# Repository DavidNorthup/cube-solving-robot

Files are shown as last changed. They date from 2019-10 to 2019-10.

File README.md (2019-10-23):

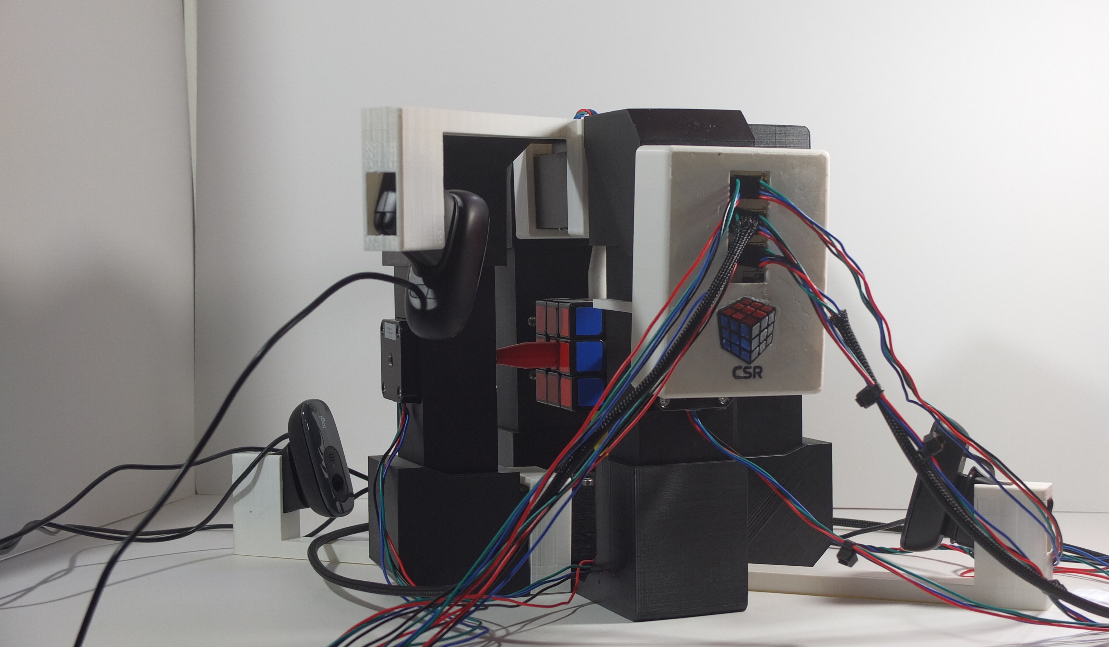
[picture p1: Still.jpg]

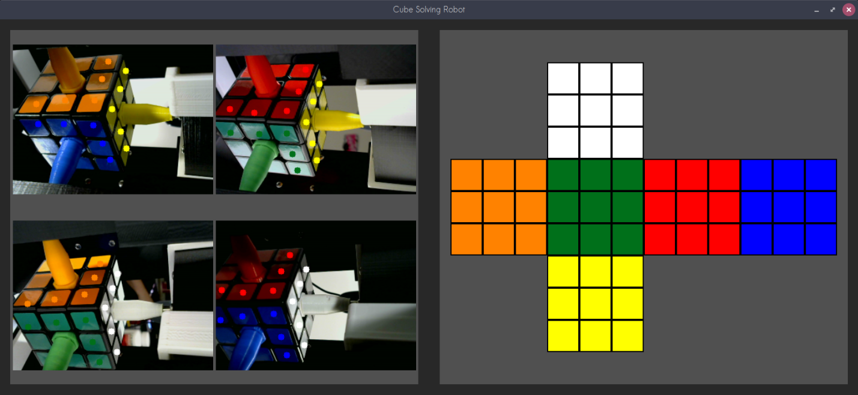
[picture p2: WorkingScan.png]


# cube-solving-robot
A personal project involving building a robot that solves the rubik's cube puzzle. There are three major components to this project. There are the robot parts themselves, the arduino code that controls the motion of the robot, and the desktop application that is used to control the robot and solve the puzzles. The application software and additional arduino libraries are written in c++. There are also a few utilities that I have included to make certain tasks more automatic. View a solve [here](https://youtu.be/WDEkHynfurc).

# Dependencies:
The arduino itself is only dependent on the arduino libraries included with the default IDE. 

The desktop application requires the following additional libraries:
[OpenCV](https://opencv.org/), [SFML](https://www.sfml-dev.org/), and [ckociemba](https://github.com/muodov/kociemba), a fast implementation of the two phase algorithm for solving rubik's cube puzzles.

# Utilities

The utilities that I have included to make tasks easier are the Sampling helper (compiled with make sampling-config.exe) and the Mask Viewer (compiled with make training-mask.exe).

## Sampling Helper
This file is meant to be run with an image captured from the webcam you are attempting to pinpoint sampling centers from. The inteded usage is to create a file that can be read on startup with the locations of points that are relevant to the scanning of the cube. For example: If you run the main desktop application, and press ctrl + s, the application will save the captured frame from the wecam to a file called "sample.jpg". Then if you wanted to create a locations file called "sampling-locations.dat" you could simply run the command: "./sampling-config.exe sample_flu.jpg > sampling-locations-flu.dat". Then when the image appears, click on the points that you wish to be sampling locations, and then close the window.

## Mask Viewer
The current implementation of the software uses opencv to select ranges of pixels defined by HSV value bounds in "Camera.h" for each of the colors on the cube. Opencv iterates through the image once for each color and generates a binary matrix of pixels with value 0 everywhere any given pixel is outside of the bounds for the speicifed color. Then it uses the sampling centers to count the number of pixels in range inside each circle defined by the center and a radius that match each color. The software then counts the number of matches for each color and whichever is highest is determined as the color for that point. This utility allows you to see the masks for a given sample image, and then reveals what it would conclude given the current bounds. Example usage is: ./training-mask.exe [image_file] [sampling locations].

# Installation Details:
1.) The first step is to install opencv, I used [this page](https://docs.opencv.org/master/d7/d9f/tutorial_linux_install.html).

2.) Install SFML, I used my package manager to install using: apt-get install libsfml-dev.

3.) Clone this repository and the kociemba repository, and make the target within 'ckociemba'.

4.) Place the executable compiled in hte step prior into the application directory.

5.) Compile all of the executables within the application directory.

6.) Install the arduino software on the boards, with the sketch and libraries included.

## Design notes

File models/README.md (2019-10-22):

# Building the robot.
I created all of these models from scratch using Autodesk Fusion 360 in parametric mode. I printed all of the parts on a Creality CR-10.

## Parts required
* 6 Main Body
* 4 Connector
* 2 Connector Loose
* 6 Cube Turner Tri Fork
* 6 Axel Tri Forks
* 2 Camera Mounts
* 2 Flipped Camera Mounts

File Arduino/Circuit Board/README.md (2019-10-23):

This folder contains the files that I used to get the PCB for the arduino and motor controllers designed and fabricated.

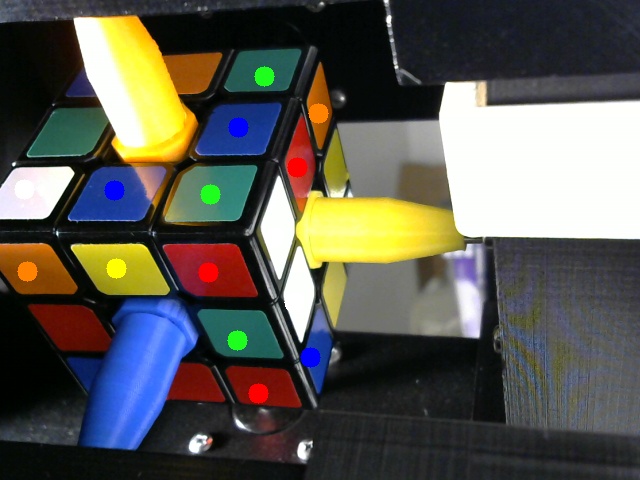
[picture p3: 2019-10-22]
application/sample.jpg

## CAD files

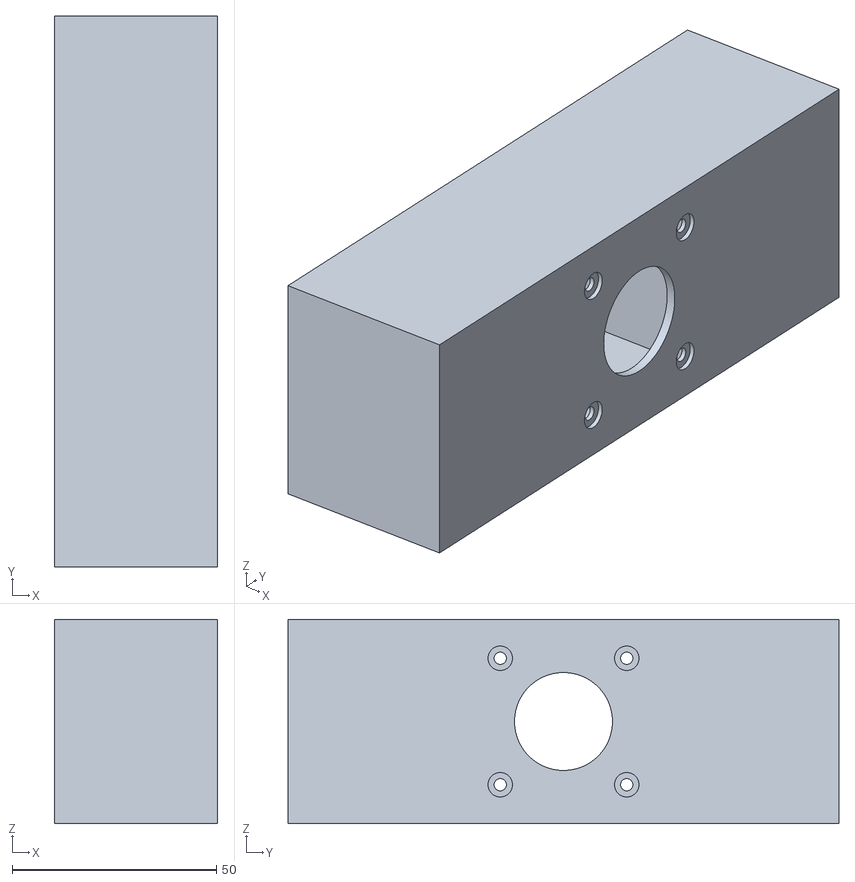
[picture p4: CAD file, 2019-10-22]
models/Main Body.stl
40.0 x 135.0 x 50.0

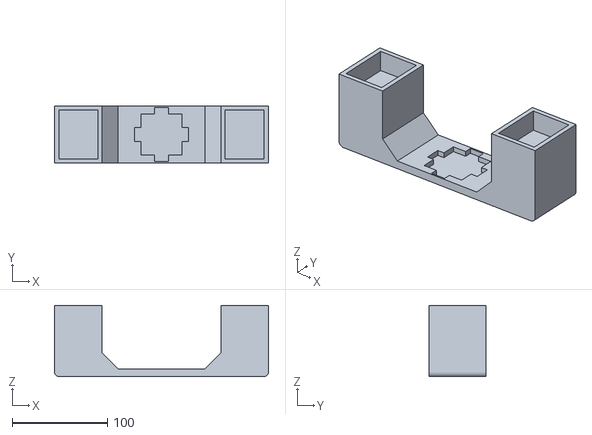
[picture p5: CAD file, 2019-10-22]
models/Connector Loose.stl
225.0 x 60.0 x 75.0

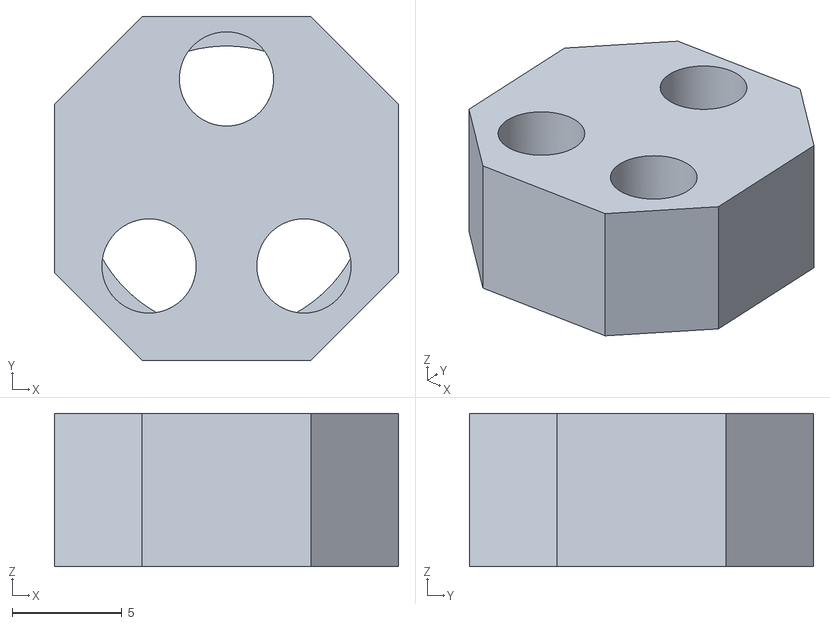
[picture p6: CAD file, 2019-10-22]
models/Cube Turner Tri Fork.stl
15.7 x 15.7 x 7.00

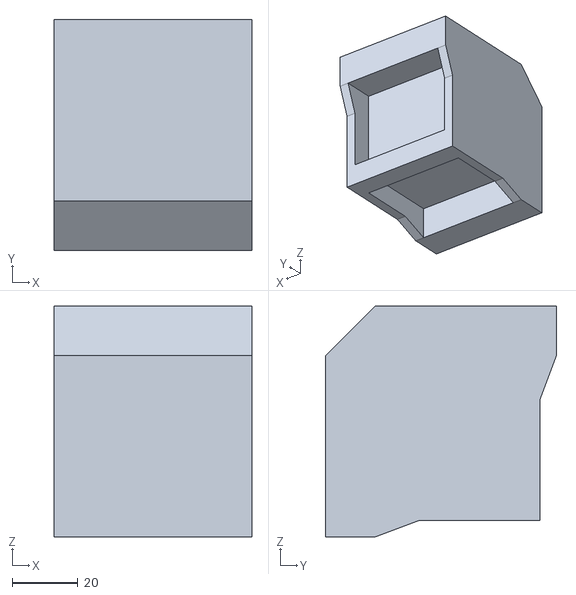
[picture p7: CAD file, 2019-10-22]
models/Connector.stl
60.0 x 70.0 x 70.0

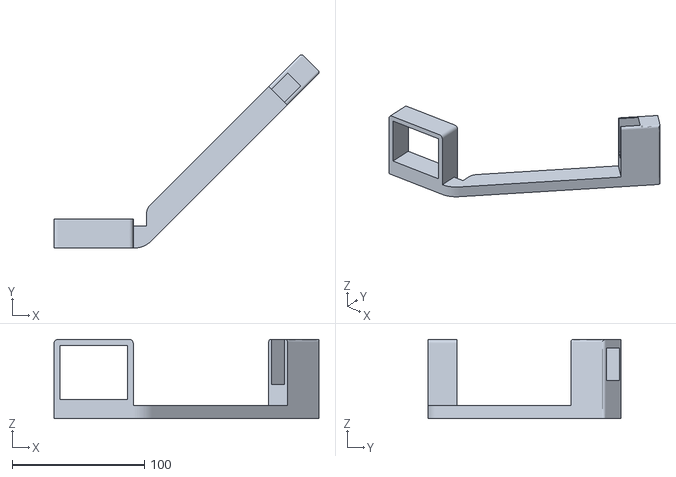
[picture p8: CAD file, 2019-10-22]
models/Camera_Mount.stl
200.6 x 146.5 x 60.0

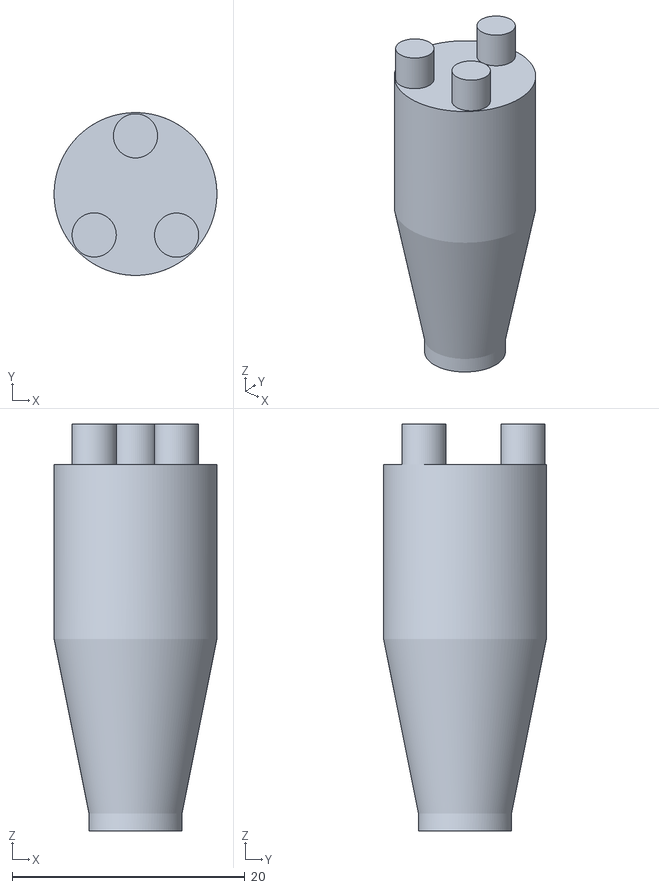
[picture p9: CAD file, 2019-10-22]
models/Axel Tri Fork.stl
14.0 x 14.0 x 35.0

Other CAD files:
models/Camera_Mount_Flipped.stl

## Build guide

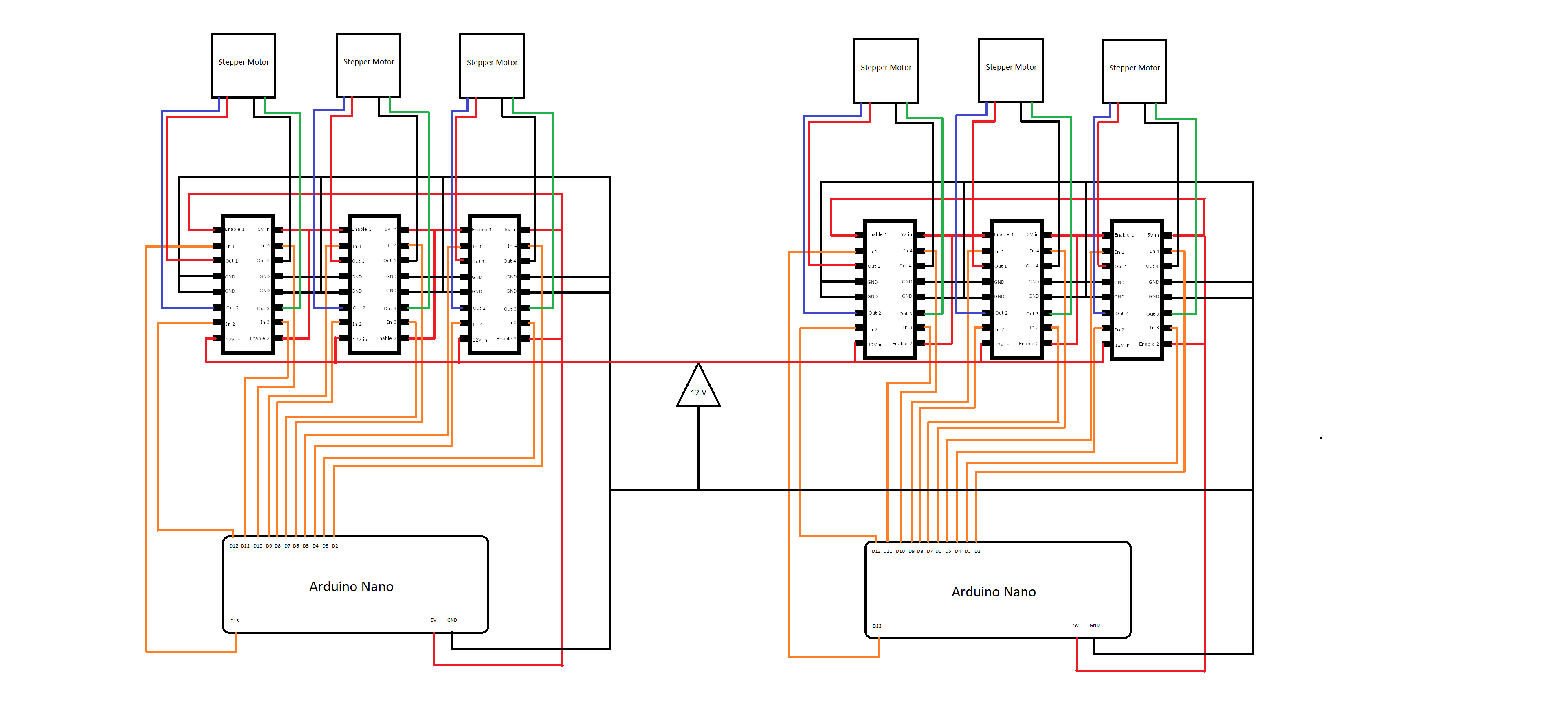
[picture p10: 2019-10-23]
Arduino/Circuit Board/Full Setup.png

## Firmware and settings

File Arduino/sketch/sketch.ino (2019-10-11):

#include <MyStepper.h>

#define STEPS_PER_QUARTER_TURN 50

int identifier = 1; // 1 for LR, 2 for FB

int motor1_pins[] = {10,12,11,13};
int motor2_pins[] = {9,7,8,6};
int motor3_pins[] = {2,4,3,5};

StepperMotor motor1(motor1_pins);
StepperMotor motor2(motor2_pins);
StepperMotor motor3(motor3_pins);

void setup() {
  // put your setup code here, to run once:
  for (int i = 0; i < PINS_PER_STEPPER; i++) {
    pinMode(motor1_pins[i], OUTPUT);
    pinMode(motor2_pins[i], OUTPUT);
    pinMode(motor3_pins[i], OUTPUT);  
  }
  Serial.begin(9600);
}

void loop() {
  if (Serial.available()) {
    int num_read = Serial.read();
    if (num_read != 255) {
      // Parse the message
      int motor_index = num_read & 3;
      bool dir_clockwise = ((num_read & 4) >> 2) == 1;
      int quarter_turns = (num_read >> 3);

      if (motor_index == 0) {
        motor1.step(dir_clockwise, quarter_turns * STEPS_PER_QUARTER_TURN);
      }
      if (motor_index == 1) {
        motor2.step(dir_clockwise, quarter_turns * STEPS_PER_QUARTER_TURN);
      }
      if (motor_index == 2) {
        motor3.step(dir_clockwise, quarter_turns * STEPS_PER_QUARTER_TURN);  
      }
      if (motor_index == 3) {
        if (dir_clockwise) {
          StepperMotor::step_two_motors(motor3, motor2, quarter_turns * 50);
        } else {
          StepperMotor::step_two_motors(motor2, motor3, quarter_turns * 50);
        }
      }
      Serial.print((char) num_read);
    } else {
      Serial.print((char)identifier);  
    }  
  }
}

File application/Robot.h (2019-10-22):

/*
This file implements all of the specific information that is going to be needed in order
to control the robot implementation. It is designed to interface the rest of the application
to the CSR robot itself.

*/

#include "SerialCommunication.h"
#include <stdlib.h>

// This number represents the minimum number of microseconds to pause to allow the arduino's 
// to reset after connecting to them.
#define PAUSE_DURATION 3*1000*1000

// These two macros are the expected values when we ping 
// the SerialManagers with message value "IDENTIFICATION_PACKET", and are
// used to determine which arduino is which, regardless of what ports they are plugged into.
#define LR_IDENTIFIER 1
#define FB_IDENTIFIER 2

// The following macros are values that can be added together in order to form a command 
// that fits within one byte.

// The two least significant bits index the motor within the controller [1-3]
#define MOTOR_1 0
#define MOTOR_2 1
#define MOTOR_3 2

// The next least significant bit identifies the direction of travel
#define DIRECTION_CLOCKWISE 0
#define DIRECTION_COUNTERCLOCKWISE (1 << 2)

// The remaining bits store the number of quarter turns desired, or in the case
// of zero, the special value used by the separator motors for separation purposes
// in the slower (ruku style) configuration. 
#define ONE_QUARTER_TURN (1 << 3)
#define TWO_QUARTER_TURNS (2 << 3)
#define THREE_QUARTER_TURNS (3 << 3)
#define FOUR_QUARTER_TURNS (4 << 3)

// Definitions for all of the valid cube moves
#define MOVE_R MOTOR_3 + DIRECTION_CLOCKWISE + ONE_QUARTER_TURN, LR_IDENTIFIER
#define MOVE_R_PRIME MOTOR_3 + DIRECTION_COUNTERCLOCKWISE + ONE_QUARTER_TURN, LR_IDENTIFIER
#define MOVE_R2 MOTOR_3 + DIRECTION_CLOCKWISE + TWO_QUARTER_TURNS, LR_IDENTIFIER

#define MOVE_L MOTOR_2 + DIRECTION_COUNTERCLOCKWISE + ONE_QUARTER_TURN, LR_IDENTIFIER
#define MOVE_L_PRIME MOTOR_2 + DIRECTION_CLOCKWISE + ONE_QUARTER_TURN, LR_IDENTIFIER
#define MOVE_L2 MOTOR_2 + DIRECTION_CLOCKWISE + TWO_QUARTER_TURNS, LR_IDENTIFIER

#define MOVE_U MOTOR_1 + DIRECTION_CLOCKWISE + ONE_QUARTER_TURN, LR_IDENTIFIER
#define MOVE_U_PRIME MOTOR_1 + DIRECTION_COUNTERCLOCKWISE + ONE_QUARTER_TURN, LR_IDENTIFIER
#define MOVE_U2 MOTOR_1 + DIRECTION_CLOCKWISE + TWO_QUARTER_TURNS, LR_IDENTIFIER

#define MOVE_F MOTOR_3 + DIRECTION_CLOCKWISE + ONE_QUARTER_TURN, FB_IDENTIFIER
#define MOVE_F_PRIME MOTOR_3 + DIRECTION_COUNTERCLOCKWISE + ONE_QUARTER_TURN, FB_IDENTIFIER
#define MOVE_F2 MOTOR_3 + DIRECTION_CLOCKWISE + TWO_QUARTER_TURNS, FB_IDENTIFIER

#define MOVE_B MOTOR_2 + DIRECTION_COUNTERCLOCKWISE + ONE_QUARTER_TURN, FB_IDENTIFIER
#define MOVE_B_PRIME MOTOR_2 + DIRECTION_CLOCKWISE + ONE_QUARTER_TURN, FB_IDENTIFIER
#define MOVE_B2 MOTOR_2 + DIRECTION_COUNTERCLOCKWISE + TWO_QUARTER_TURNS, FB_IDENTIFIER

#define MOVE_D MOTOR_1 + DIRECTION_CLOCKWISE + ONE_QUARTER_TURN, FB_IDENTIFIER
#define MOVE_D_PRIME MOTOR_1 + DIRECTION_COUNTERCLOCKWISE + ONE_QUARTER_TURN, FB_IDENTIFIER
#define MOVE_D2 MOTOR_1 + DIRECTION_CLOCKWISE + TWO_QUARTER_TURNS, FB_IDENTIFIER 

#define MOVES {"R", "R'", "R2", "L", "L'", "L2", "F", "F'", "F2", "B", "B'", "B2", "U", "U'", "U2", "D", "D'", "D2"}

#define SCRAMBLE_LENGTH 20

// So for example if we wanted to perform a move on motor 2, clockwise, with 3 quarter turns,
// we would pass the following into the sendCommand function: MOTOR_2 + DIRECTION_CLOCKWISE + THREE_QUARTER_TURNS

namespace csr{

class Robot {
    public:
    Robot(std::string port1, std::string port2);
    ~Robot();
    bool sendCommand(uint16_t command, uint16_t smIdentifier);
    void performMove(std::string move);
    std::string reverseMove(std::string move);
    std::string performMoves(std::string moves);
    std::string scramble(int len);

    private:
    communication::SerialManager * lr_manager;
    communication::SerialManager * fb_manager;
};

}

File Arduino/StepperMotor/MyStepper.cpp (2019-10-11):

#include "Arduino.h"
#include "MyStepper.h"

#define STEPPER_DELAY 1500 // This is in microseconds
#define STEPPER_MIN_DELAY 500

/*
This is the constructor for the stepper motor object. There is only one 
constructor and it takes an integer array as a parameter, which corresponds
to a ordered list of pin numbers connected to the arduino, which corresponds to
the order needed to proceed in to produce motion in the clockwise direction,
so for example if we have the input:

pins_clockwise: [1,2,3,4]

Then if we activate the pins by themselves in the order 1-2-3-4,
then we produce a clockwise rotation on the motor.
*/
StepperMotor::StepperMotor(int pins_clockwise[]) {
    for(int j = 0; j < PINS_PER_STEPPER; j++) {
        this->pins_clockwise[j] = pins_clockwise[j];
        this->pins_cclockwise[j] = pins_clockwise[PINS_PER_STEPPER - 1 - j];
    }
    
    i = 0;
    for (int j = 0; j < PINS_PER_STEPPER; j++) {
        pinMode(pins_clockwise[j], OUTPUT);
    }
}

int StepperMotor::calc_delay(int x, int n) {
    double xm = x - (n/2);
    return (int) ((4.0 * xm * xm * (STEPPER_DELAY - STEPPER_MIN_DELAY)) / (n * n) + STEPPER_MIN_DELAY);
}

/*
This function steps the specified motor clockwise if the boolean parameter is true,
or counter-clockwise if it is given as false. It steps the motor the specified number
of steps.
*/
void StepperMotor::step(bool clockwise, int num_steps) {    

    delayMicroseconds(STEPPER_DELAY);
    for (int j = 0; j < num_steps; j++) {
        one_step(clockwise);
        delayMicroseconds(calc_delay(j, num_steps));
    }
    shutoff();
}

/* 
This function steps two stepper motors at the exact same time. The first parameter 
represents the stepper motor that is going to be going clockwise, and the second motor 
is one that will go counterclockwise. The number of steps is the number of steps that each
motor will perform.
*/
void StepperMotor::step_two_motors(StepperMotor clockwise_motor, StepperMotor counter_motor, int number_steps) {
    for (int j = 0; j < number_steps; j++) {
        clockwise_motor.one_step(true);
        counter_motor.one_step(false);
        delayMicroseconds(STEPPER_DELAY);
    }
    clockwise_motor.shutoff();
    counter_motor.shutoff();
}

/*
This function turns the motor off, by nullifying all of the output signals to the given
pins.
*/
void StepperMotor::shutoff() {
    for (int j = 0; j < PINS_PER_STEPPER; j++) {
        digitalWrite(pins_clockwise[j], LOW); 
    }  
}

void StepperMotor::hold() {
    for (int j = 0; j < PINS_PER_STEPPER; j++) {
        if (j != i) {
            digitalWrite(pins_clockwise[j] , LOW);
        } else {
            digitalWrite(pins_clockwise[j], HIGH);
        }
    }
}



/*
This function rotates the stepper motor one single step in the specified direction. 
*/
void StepperMotor::one_step(bool clockwise) {
    int step1 = i;
    int step2 = (i + 1) % PINS_PER_STEPPER;
    

    int * pins;
    if (clockwise) {
        pins = pins_clockwise;
    } else {
        pins = pins_cclockwise;
    }

    for (int j = 0; j < 4; j++) {
        if (j != step1 && j != step2) {
            digitalWrite(pins[j], LOW);  
        }   
    }

    digitalWrite(pins[step1], HIGH);
    digitalWrite(pins[step2], HIGH);
    i = step2;
}

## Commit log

2019-07-14 Added selection of device for output testing
2019-07-17 Added stepper motor library
2019-07-19 Updated to support camera operations
2019-10-03 Added acceleration profile to motor control
2019-10-19 Updated color scanning mechanism, next update will include multiple camera implementation
2019-10-19 Updated readme to reflect current project improvements
2019-10-23 Added PCB Gerber Files
